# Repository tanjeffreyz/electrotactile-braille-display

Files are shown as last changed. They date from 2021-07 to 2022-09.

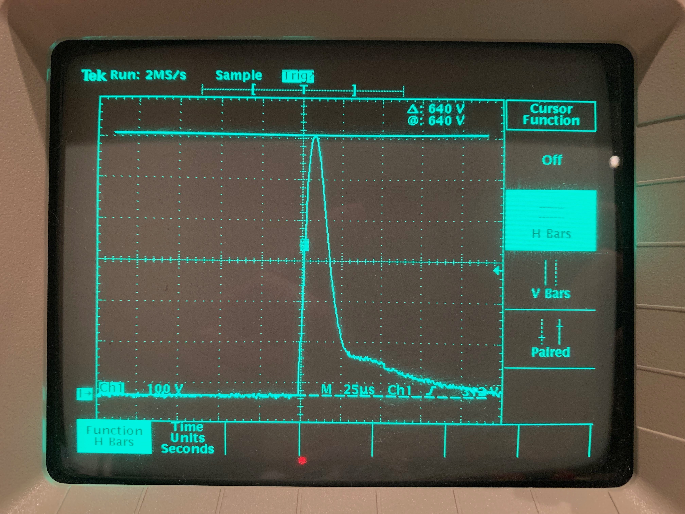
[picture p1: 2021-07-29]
images/oscilloscope_readings/IMG_0131.JPG

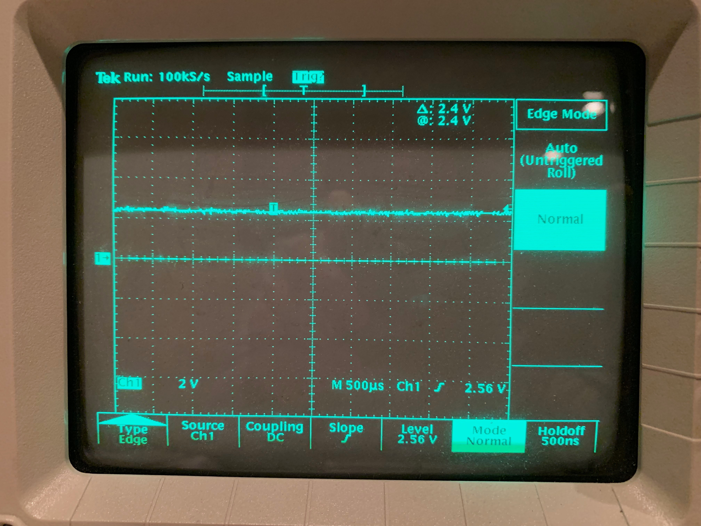
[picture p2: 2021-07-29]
images/oscilloscope_readings/IMG_0013.JPG

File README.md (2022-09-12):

<h1 align="center">Electrotactile Braille Display</h1> 

The Electrotactile Braille Display (ETBD) is a refreshable braille display that uses electrical pulses to simulate the feeling of braille dots on the user's fingertips. 
Because it has no moving parts, the ETBD has the potential to be much lighter, thinner, and cheaper compared to mechanical braille displays, which use physical braille pins.
 
<div align="center">
  
</div>
<br>
<div align="center">
  <a href="https://tanjeffreyz.github.io/electrotactile-braille-display"><b>Click here to view this project's full description</b></a>
</div>

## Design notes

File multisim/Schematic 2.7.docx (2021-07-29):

Schematic of Latest Prototype

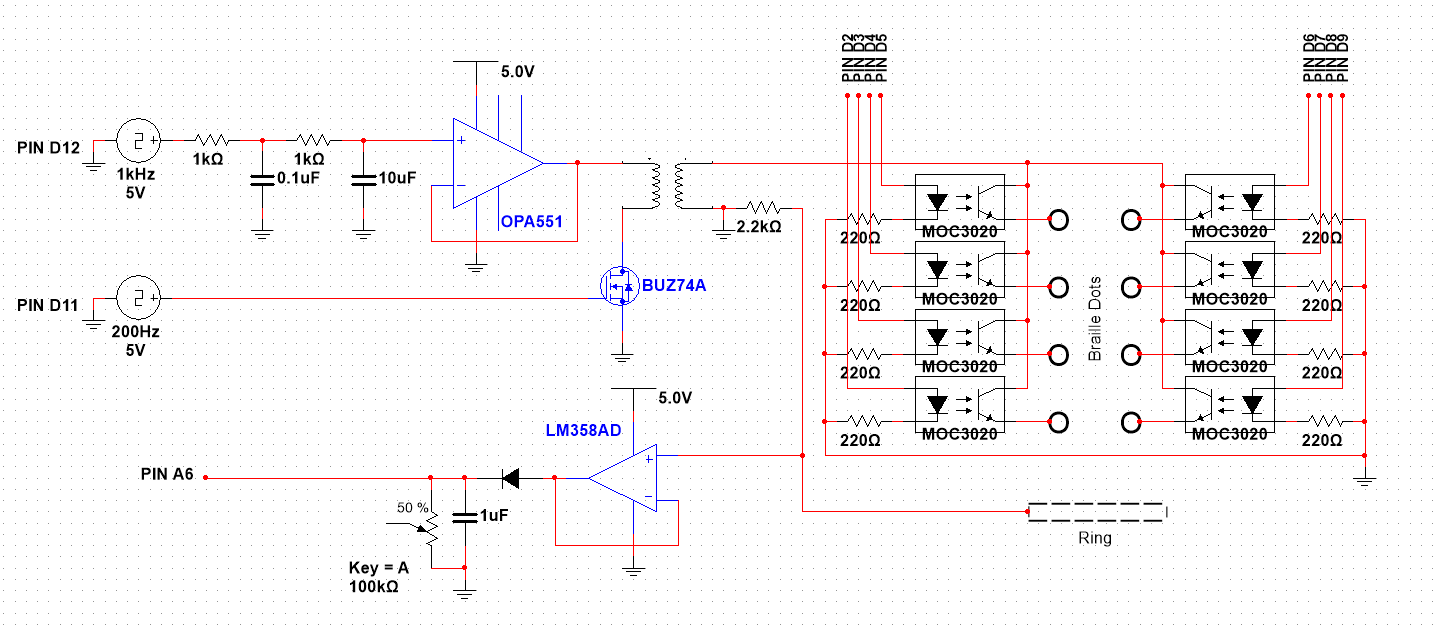
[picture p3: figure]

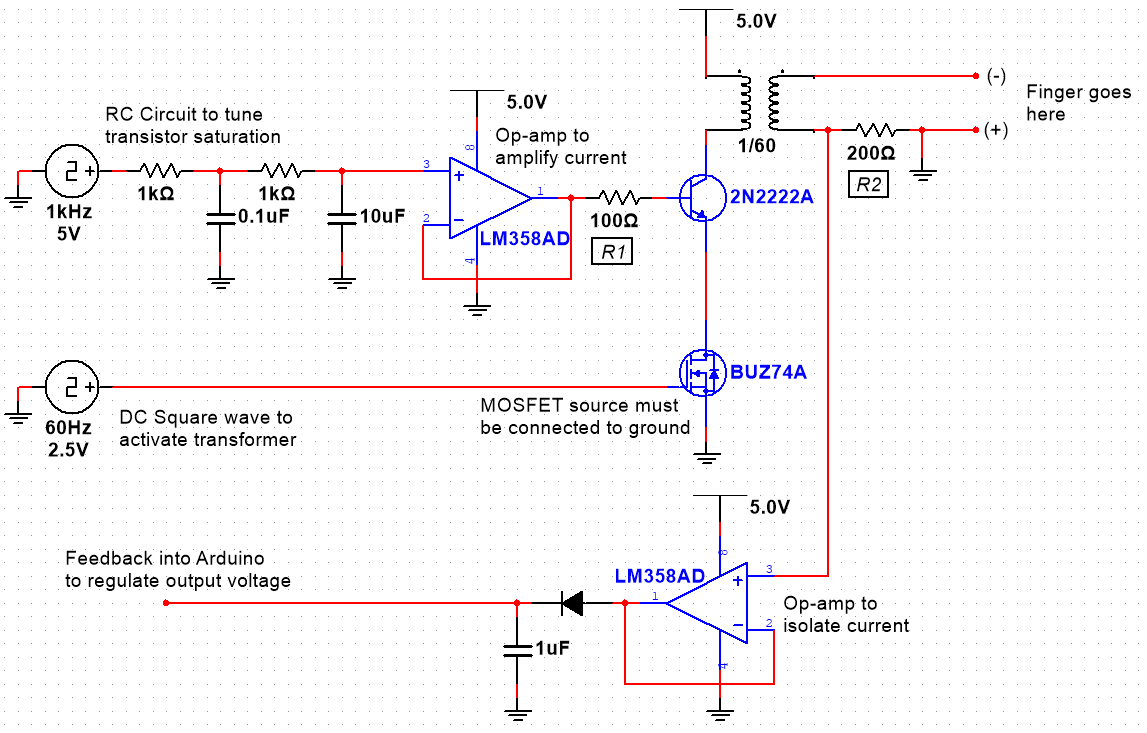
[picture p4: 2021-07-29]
images/schematics/Schematic v2.2.PNG

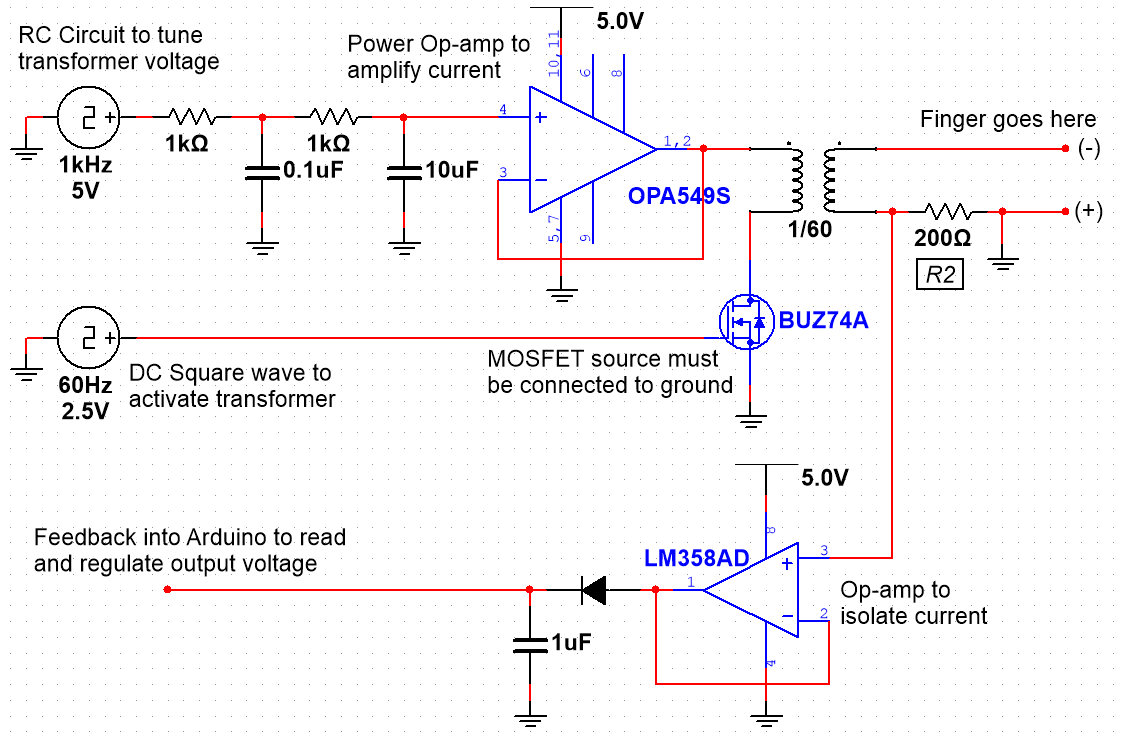
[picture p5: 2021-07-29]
images/schematics/Schematic v2.3.PNG

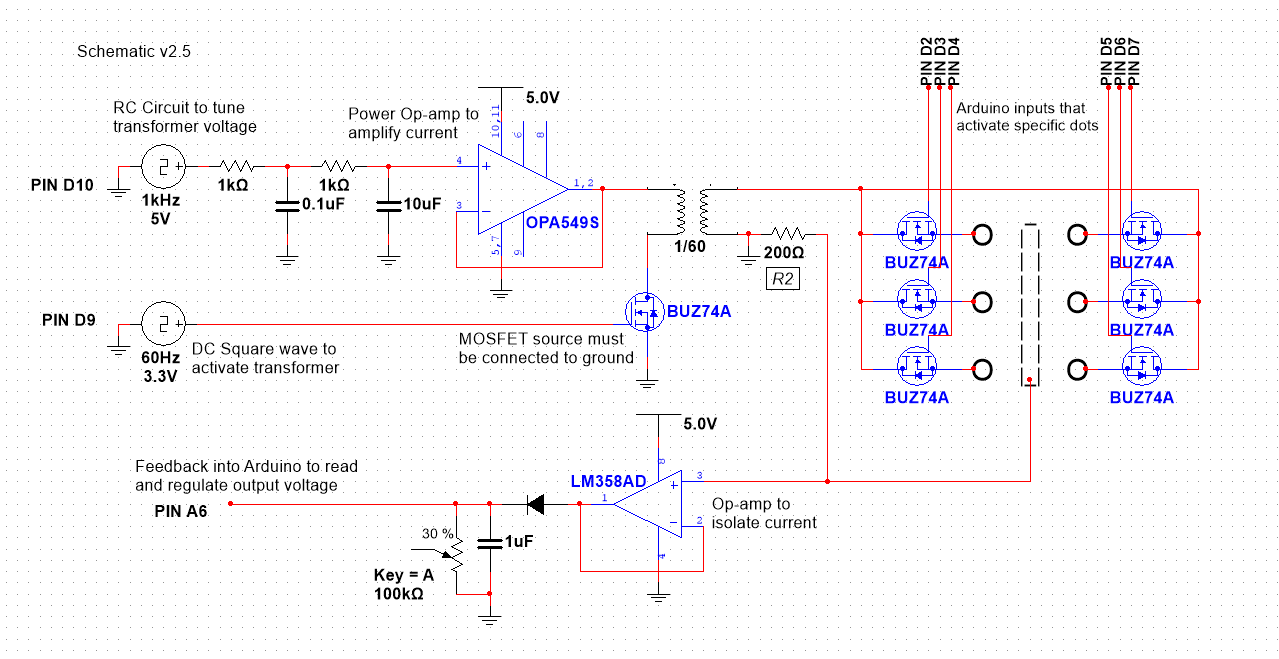
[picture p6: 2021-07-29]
images/schematics/Schematic v2.5.png

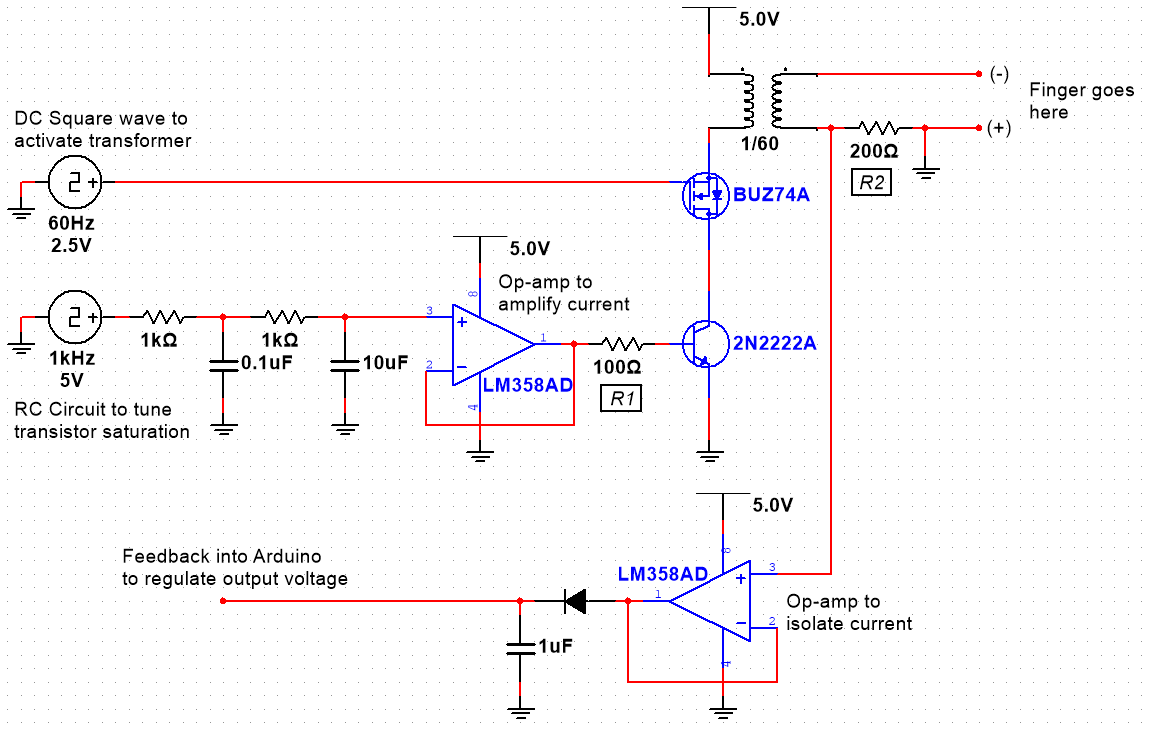
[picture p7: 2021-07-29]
images/schematics/Schematic v2.1.PNG

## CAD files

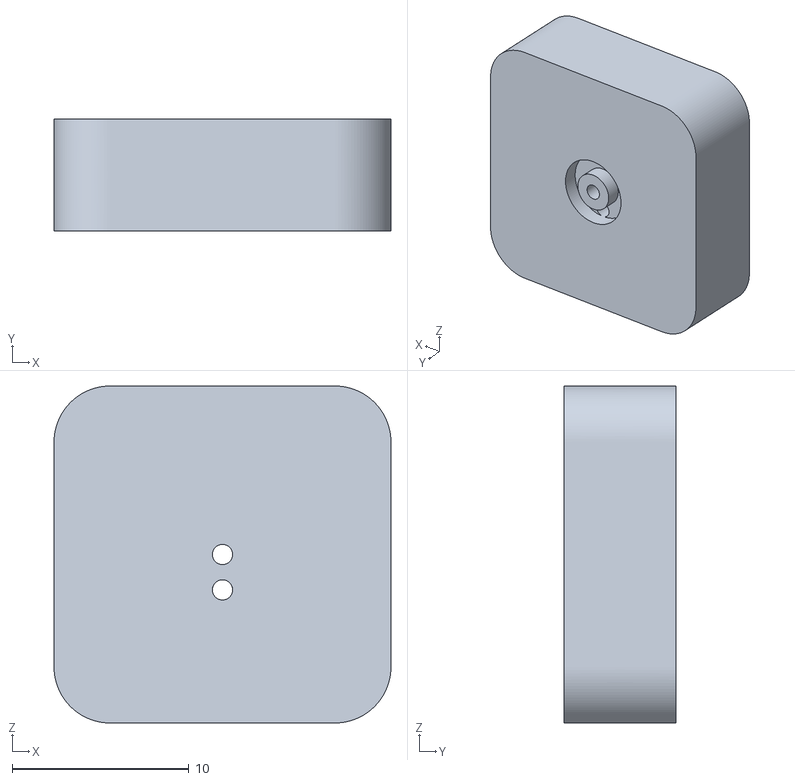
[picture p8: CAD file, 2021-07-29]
cad/Unit_v3.stl
19.0 x 6.35 x 19.0

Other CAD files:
cad/Unit_v3-1.dwg
cad/OldVersions/Unit_v3-1.0001.dwg
cad/Unit_v2.stl
cad/Unit_v1.stl
cad/OldVersions/Unit_v1.0001.ipt
cad/Unit_v1.ipt
cad/Unit_v2.ipt
cad/Unit_v3.ipt

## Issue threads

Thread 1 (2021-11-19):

Help to create a new braille device

discapacidad5, 2021-11-19:
Help to create a new braille device

Hi, I don't speak English, I'm using the google translator, I hope they understand me, my language is Spanish

I am developing a braille line with the ardiuno IDE and esp32 I have all the hardware but my problem is precisely that I do not fear how to communicate with the esp32
I have tried to connect the serial monitor of ardiuno and connect the esp32 by bluetooth and in the output of the serial port I get pure question marks and unreadable characters
I would like help to develop the software that would go in the esp32 that exchange data with the devices

my project consists of a very low cost braille display probably anyone can manufacture with less than $ 50 the idea is to create everything and make it available so that anyone can print their own braille display on a 3d printer and added the esp32 card and the driver can make your own braille line I hope someone can help me

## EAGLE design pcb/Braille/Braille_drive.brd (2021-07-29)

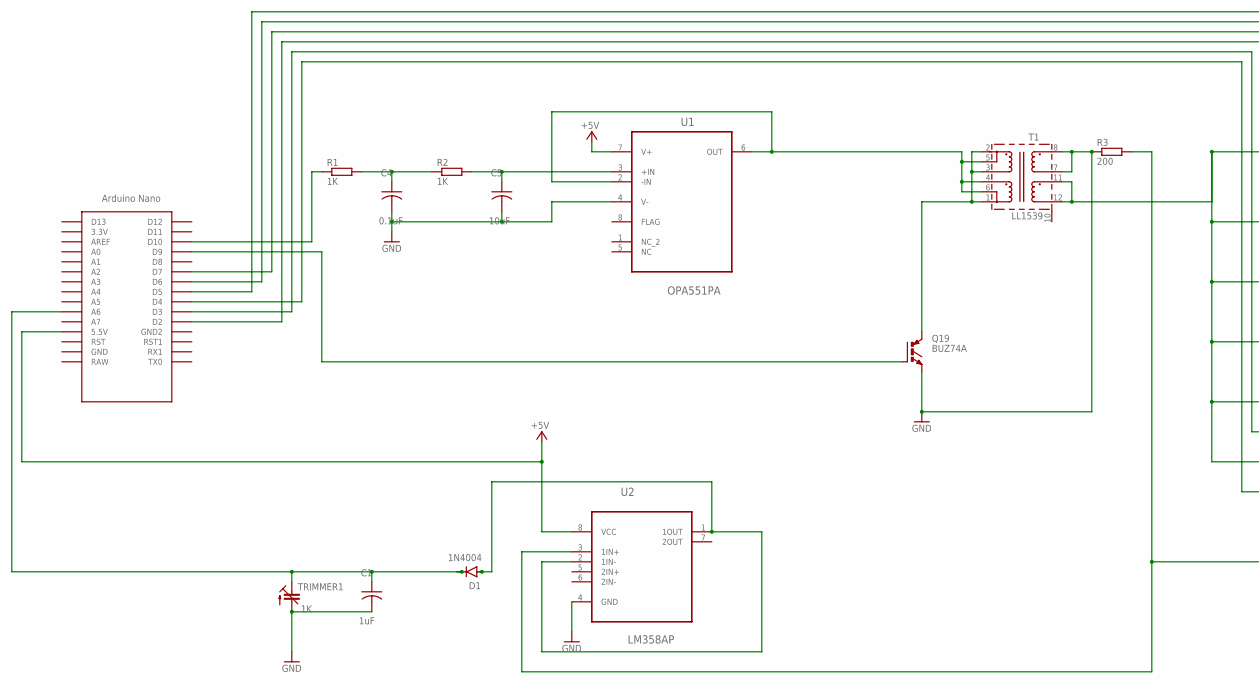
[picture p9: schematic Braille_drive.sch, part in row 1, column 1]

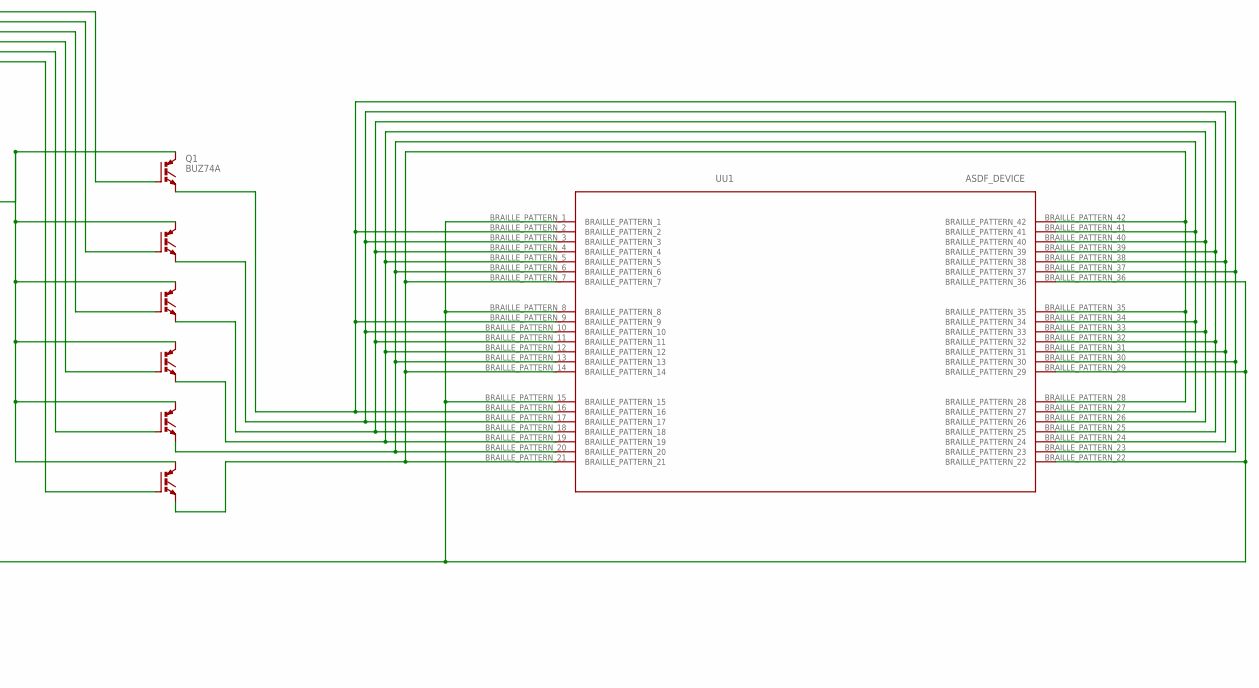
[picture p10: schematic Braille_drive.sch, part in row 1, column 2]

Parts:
C1: 1uF; CAP_RADIAL_2MM
C4: 0.1uF; CAP_RADIAL_2MM
C5: 10uF; CAP_RADIAL_2MM
D1: 1N4004; DO-41
Q1, Q2, Q3, Q4, Q5, Q6, Q19: BUZ74A; TO220AV
R1, R2: 1K; 0204V
R3: 200; 0204V
T1: LL1539
TRIMMER1: 1K; CTRIM3040.452
U1: OPA551PA; DIP254P762X508-8
U2: LM358AP; DIP254P762X508-8
U$1: NANO
UU1: ASDF_DEVICE; BRAILLE_PATTERN1

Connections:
+5V: U1.7 (V+), U2.8 (VCC), U$1.5V (5.5V)
GND: C1.2, C4.2, C5.2, Q19.E, R3.1, T1.7, T1.8, TRIMMER1.2 (A), U1.4 (V-), U2.4 (GND)
unnamed: R1.1, U$1.D10
unnamed: C4.1, R1.2, R2.1
unnamed: C5.1, R2.2, U1.3 (+IN)
unnamed: T1.4, T1.5, T1.6, U1.2 (-IN), U1.6 (OUT)
unnamed: Q19.C, T1.1, T1.2, T1.3
unnamed: Q19.G, U$1.D9
unnamed: D1.A, U2.1 (1OUT), U2.2 (1IN-)
unnamed: C1.1, D1.C, TRIMMER1.1A (E), U$1.A6
unnamed: Q6.G, U$1.D4
unnamed: Q5.G, U$1.D3
unnamed: Q1.C, Q2.C, Q3.C, Q4.C, Q5.C, Q6.C, T1.11, T1.12
unnamed: Q4.G, U$1.D2
unnamed: Q6.E, UU1.BRAILLE_PATTERN_7, UU1.BRAILLE_PATTERN_14, UU1.BRAILLE_PATTERN_21, UU1.BRAILLE_PATTERN_28, UU1.BRAILLE_PATTERN_35, UU1.BRAILLE_PATTERN_42
unnamed: Q3.G, U$1.D7
unnamed: Q2.G, U$1.D6
unnamed: Q1.G, U$1.D5
unnamed: R3.2, U2.3 (1IN+), UU1.BRAILLE_PATTERN_1, UU1.BRAILLE_PATTERN_8, UU1.BRAILLE_PATTERN_15, UU1.BRAILLE_PATTERN_22, UU1.BRAILLE_PATTERN_29, UU1.BRAILLE_PATTERN_36
unnamed: Q5.E, UU1.BRAILLE_PATTERN_6, UU1.BRAILLE_PATTERN_13, UU1.BRAILLE_PATTERN_20, UU1.BRAILLE_PATTERN_27, UU1.BRAILLE_PATTERN_34, UU1.BRAILLE_PATTERN_41
unnamed: Q1.E, UU1.BRAILLE_PATTERN_2, UU1.BRAILLE_PATTERN_9, UU1.BRAILLE_PATTERN_16, UU1.BRAILLE_PATTERN_23, UU1.BRAILLE_PATTERN_30, UU1.BRAILLE_PATTERN_37
unnamed: Q4.E, UU1.BRAILLE_PATTERN_5, UU1.BRAILLE_PATTERN_12, UU1.BRAILLE_PATTERN_19, UU1.BRAILLE_PATTERN_26, UU1.BRAILLE_PATTERN_33, UU1.BRAILLE_PATTERN_40
unnamed: Q3.E, UU1.BRAILLE_PATTERN_4, UU1.BRAILLE_PATTERN_11, UU1.BRAILLE_PATTERN_18, UU1.BRAILLE_PATTERN_25, UU1.BRAILLE_PATTERN_32, UU1.BRAILLE_PATTERN_39
unnamed: Q2.E, UU1.BRAILLE_PATTERN_3, UU1.BRAILLE_PATTERN_10, UU1.BRAILLE_PATTERN_17, UU1.BRAILLE_PATTERN_24, UU1.BRAILLE_PATTERN_31, UU1.BRAILLE_PATTERN_38

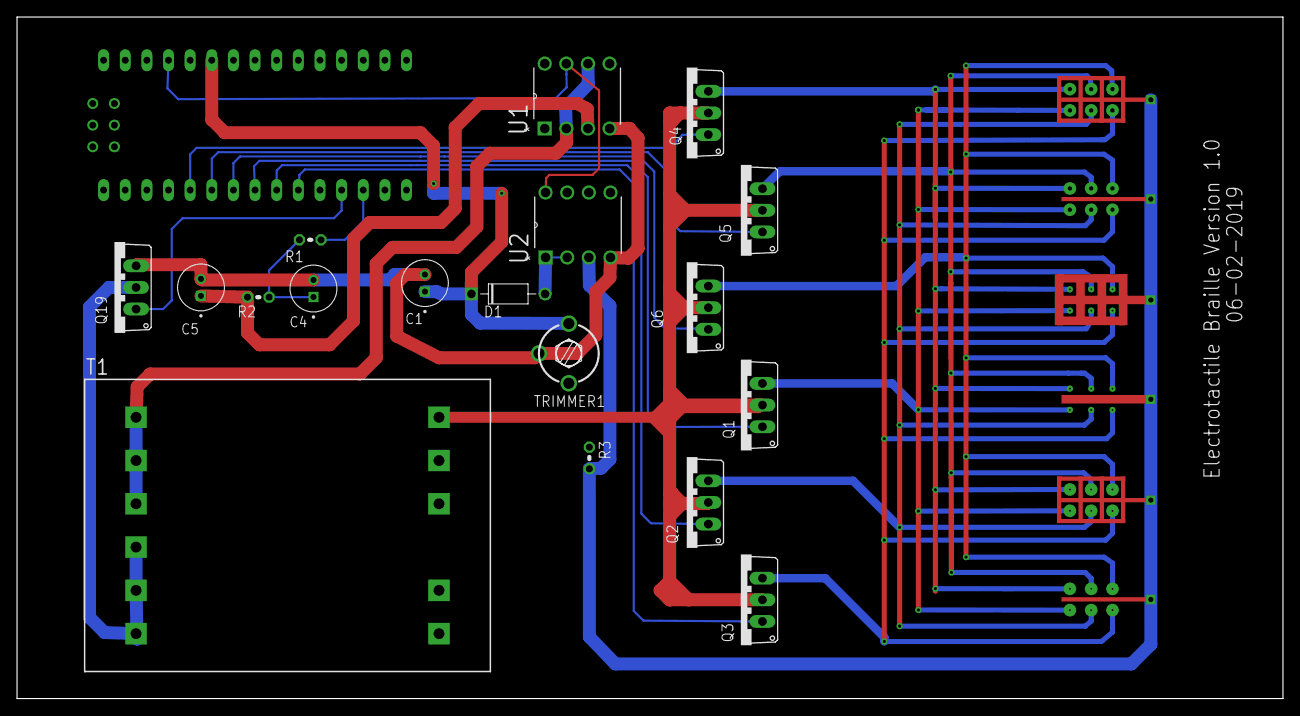
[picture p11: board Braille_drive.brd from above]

Board: 2 copper layers, 148.6 x 80.0 mm, 20 parts (0 on the bottom side), 24 nets.

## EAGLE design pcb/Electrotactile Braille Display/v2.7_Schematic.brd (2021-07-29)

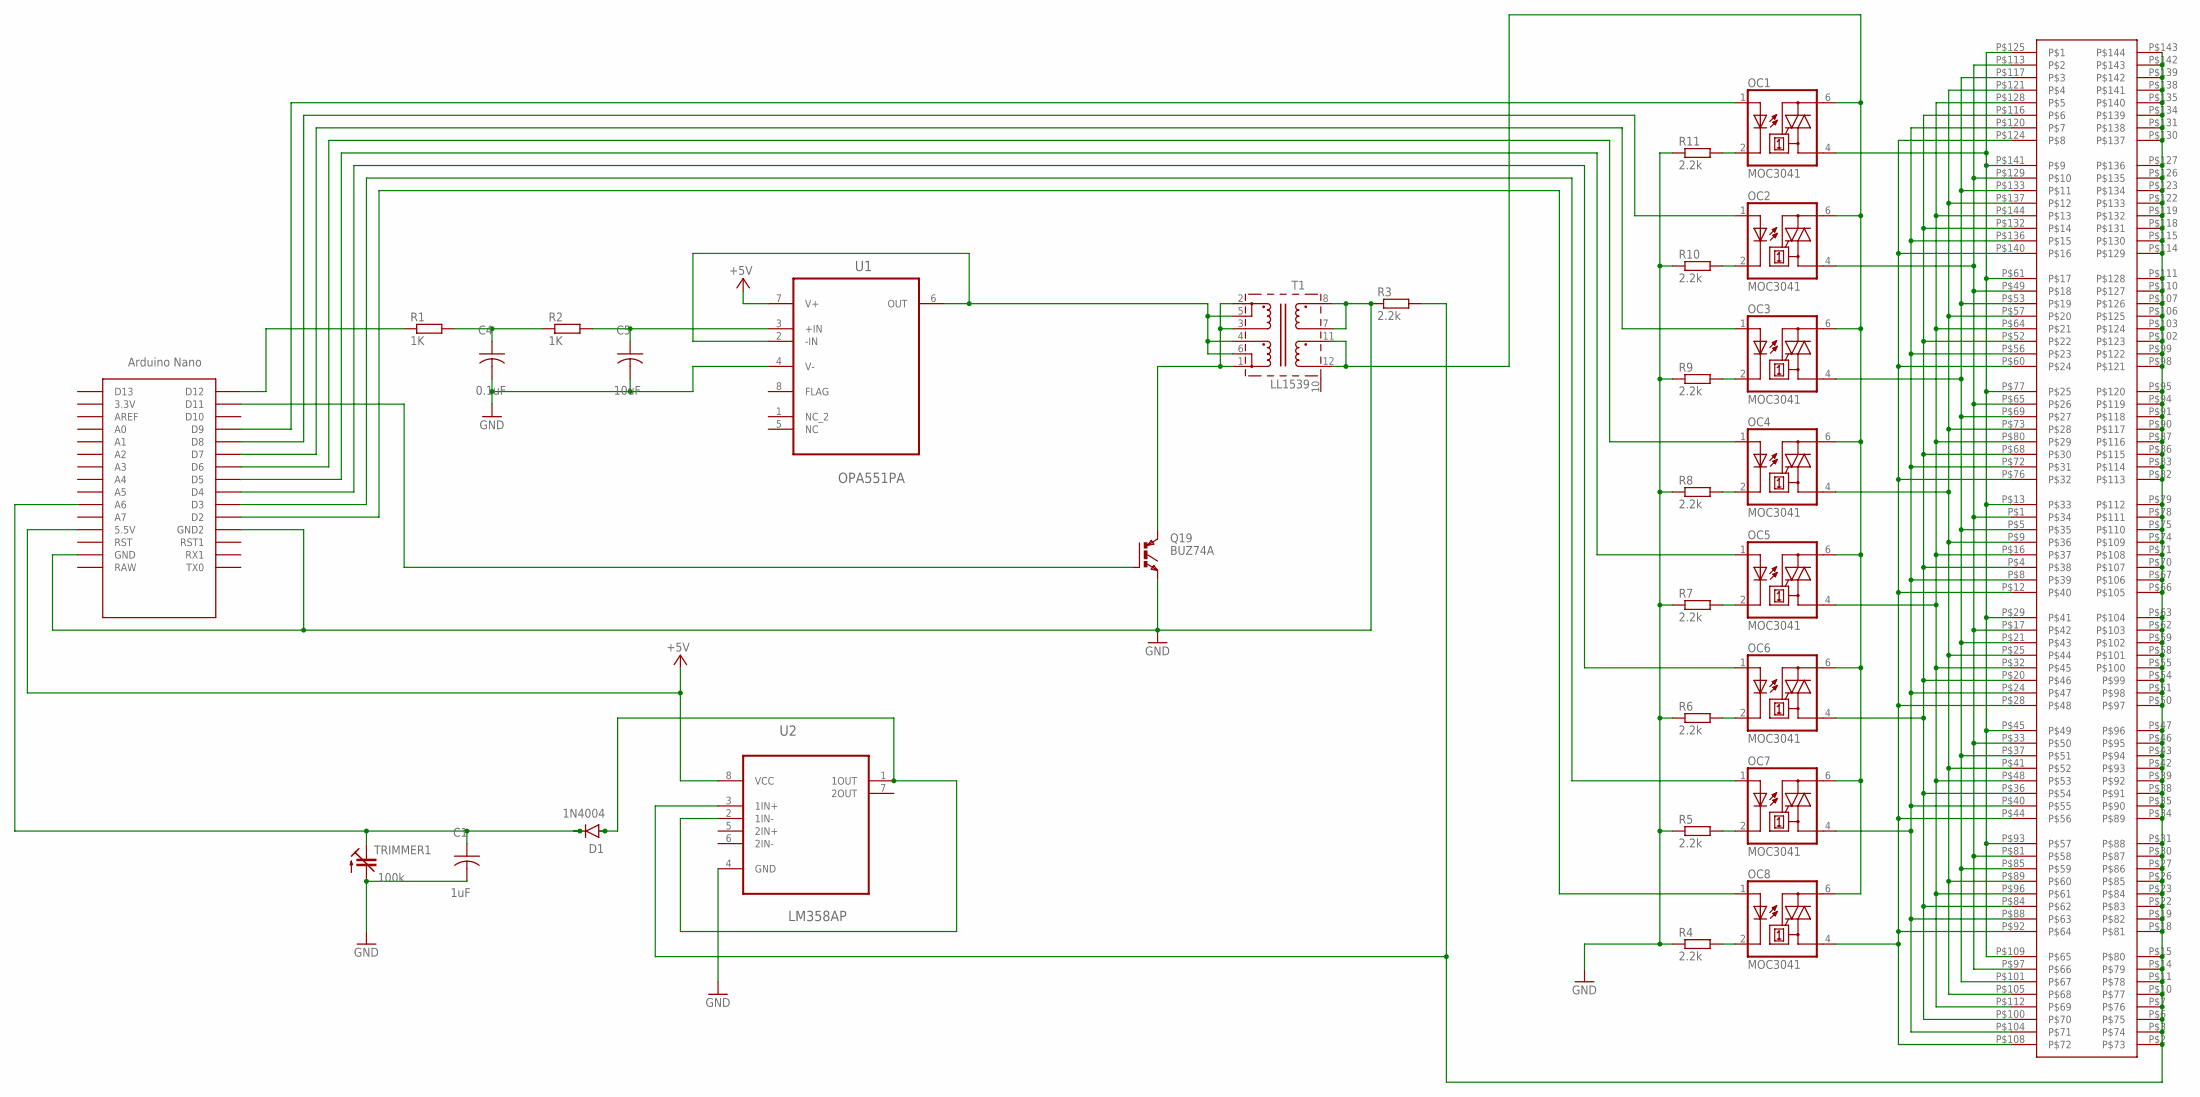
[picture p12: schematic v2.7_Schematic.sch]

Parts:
C1: 1uF; CAP_RADIAL_2MM
C4: 0.1uF; CAP_RADIAL_2MM
C5: 10uF; CAP_RADIAL_2MM
D1: 1N4004; DO-41
OC1, OC2, OC3, OC4, OC5, OC6, OC7, OC8: MOC3041; DIL06
Q19: BUZ74A; TO220AV
R1, R2: 1K; 0204V
R3, R4, R5, R6, R7, R8, R9, R10, R11: 2.2k; 0204V
T1: LL1539
TRIMMER1: 100k; CTRIM3040.452
U1: OPA551PA; DIP254P762X508-8
U2: LM358AP; DIP254P762X508-8
U$1: NANO
U$2: DOTS_V2

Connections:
+5V: U1.7 (V+), U2.8 (VCC), U$1.5V (5.5V)
GND: C1.2, C4.2, C5.2, Q19.E, R3.1, R4.1, R5.1, R6.1, R7.1, R8.1, R9.1, R10.1, R11.1, T1.7, T1.8, TRIMMER1.2 (A), U1.4 (V-), U2.4 (GND), U$1.GND, U$1.GND1 (GND2)
unnamed: OC7.2 (C), R5.2
unnamed: C4.1, R1.2, R2.1
unnamed: C5.1, R2.2, U1.3 (+IN)
unnamed: T1.4, T1.5, T1.6, U1.2 (-IN), U1.6 (OUT)
unnamed: Q19.C, T1.1, T1.2, T1.3
unnamed: Q19.G, U$1.D11
unnamed: D1.A, U2.1 (1OUT), U2.2 (1IN-)
unnamed: C1.1, D1.C, TRIMMER1.1A (E), U$1.A6
unnamed: OC8.1 (A), U$1.D2
unnamed: OC7.1 (A), U$1.D3
unnamed: OC2.1 (A), U$1.D8
unnamed: OC6.1 (A), U$1.D4
unnamed: R1.1, U$1.D12
unnamed: OC5.1 (A), U$1.D5
unnamed: OC4.1 (A), U$1.D6
unnamed: OC3.1 (A), U$1.D7
unnamed: R3.2, U2.3 (1IN+), U$2.P$2, U$2.P$3, U$2.P$6, U$2.P$7, U$2.P$10, U$2.P$11, U$2.P$14, U$2.P$15, U$2.P$18, U$2.P$19, U$2.P$22, U$2.P$23, U$2.P$26, U$2.P$27, U$2.P$30, U$2.P$31, U$2.P$34, U$2.P$35, U$2.P$38, U$2.P$39, U$2.P$42, U$2.P$43, U$2.P$46, U$2.P$47, U$2.P$50, U$2.P$51, U$2.P$54, U$2.P$55, U$2.P$58, U$2.P$59, U$2.P$62, U$2.P$63, U$2.P$66, U$2.P$67, U$2.P$70, U$2.P$71, U$2.P$74, U$2.P$75, U$2.P$78, U$2.P$79, U$2.P$82, U$2.P$83, U$2.P$86, U$2.P$87, U$2.P$90, U$2.P$91, U$2.P$94, U$2.P$95, U$2.P$98, U$2.P$99, U$2.P$102, U$2.P$103, U$2.P$106, U$2.P$107, U$2.P$110, U$2.P$111, U$2.P$114, U$2.P$115, U$2.P$118, U$2.P$119, U$2.P$122, U$2.P$123, U$2.P$126, U$2.P$127, U$2.P$130, U$2.P$131, U$2.P$134, U$2.P$135, U$2.P$138, U$2.P$139, U$2.P$142, U$2.P$143
unnamed: OC1.6 (A2), OC2.6 (A2), OC3.6 (A2), OC4.6 (A2), OC5.6 (A2), OC6.6 (A2), OC7.6 (A2), OC8.6 (A2), T1.11, T1.12
unnamed: OC4.4 (A1), U$2.P$9, U$2.P$25, U$2.P$41, U$2.P$57, U$2.P$73, U$2.P$89, U$2.P$105, U$2.P$121, U$2.P$137
unnamed: OC1.1 (A), U$1.D9
unnamed: OC2.4 (A1), U$2.P$1, U$2.P$17, U$2.P$33, U$2.P$49, U$2.P$65, U$2.P$81, U$2.P$97, U$2.P$113, U$2.P$129
unnamed: OC3.4 (A1), U$2.P$5, U$2.P$21, U$2.P$37, U$2.P$53, U$2.P$69, U$2.P$85, U$2.P$101, U$2.P$117, U$2.P$133
unnamed: OC5.4 (A1), U$2.P$16, U$2.P$32, U$2.P$48, U$2.P$64, U$2.P$80, U$2.P$96, U$2.P$112, U$2.P$128, U$2.P$144
unnamed: OC6.4 (A1), U$2.P$4, U$2.P$20, U$2.P$36, U$2.P$52, U$2.P$68, U$2.P$84, U$2.P$100, U$2.P$116, U$2.P$132
unnamed: OC7.4 (A1), U$2.P$8, U$2.P$24, U$2.P$40, U$2.P$56, U$2.P$72, U$2.P$88, U$2.P$104, U$2.P$120, U$2.P$136
unnamed: OC8.4 (A1), U$2.P$12, U$2.P$28, U$2.P$44, U$2.P$60, U$2.P$76, U$2.P$92, U$2.P$108, U$2.P$124, U$2.P$140
unnamed: OC8.2 (C), R4.2
unnamed: OC1.4 (A1), U$2.P$13, U$2.P$29, U$2.P$45, U$2.P$61, U$2.P$77, U$2.P$93, U$2.P$109, U$2.P$125, U$2.P$141
unnamed: OC6.2 (C), R6.2
unnamed: OC5.2 (C), R7.2
unnamed: OC4.2 (C), R8.2
unnamed: OC3.2 (C), R9.2
unnamed: OC2.2 (C), R10.2
unnamed: OC1.2 (C), R11.2

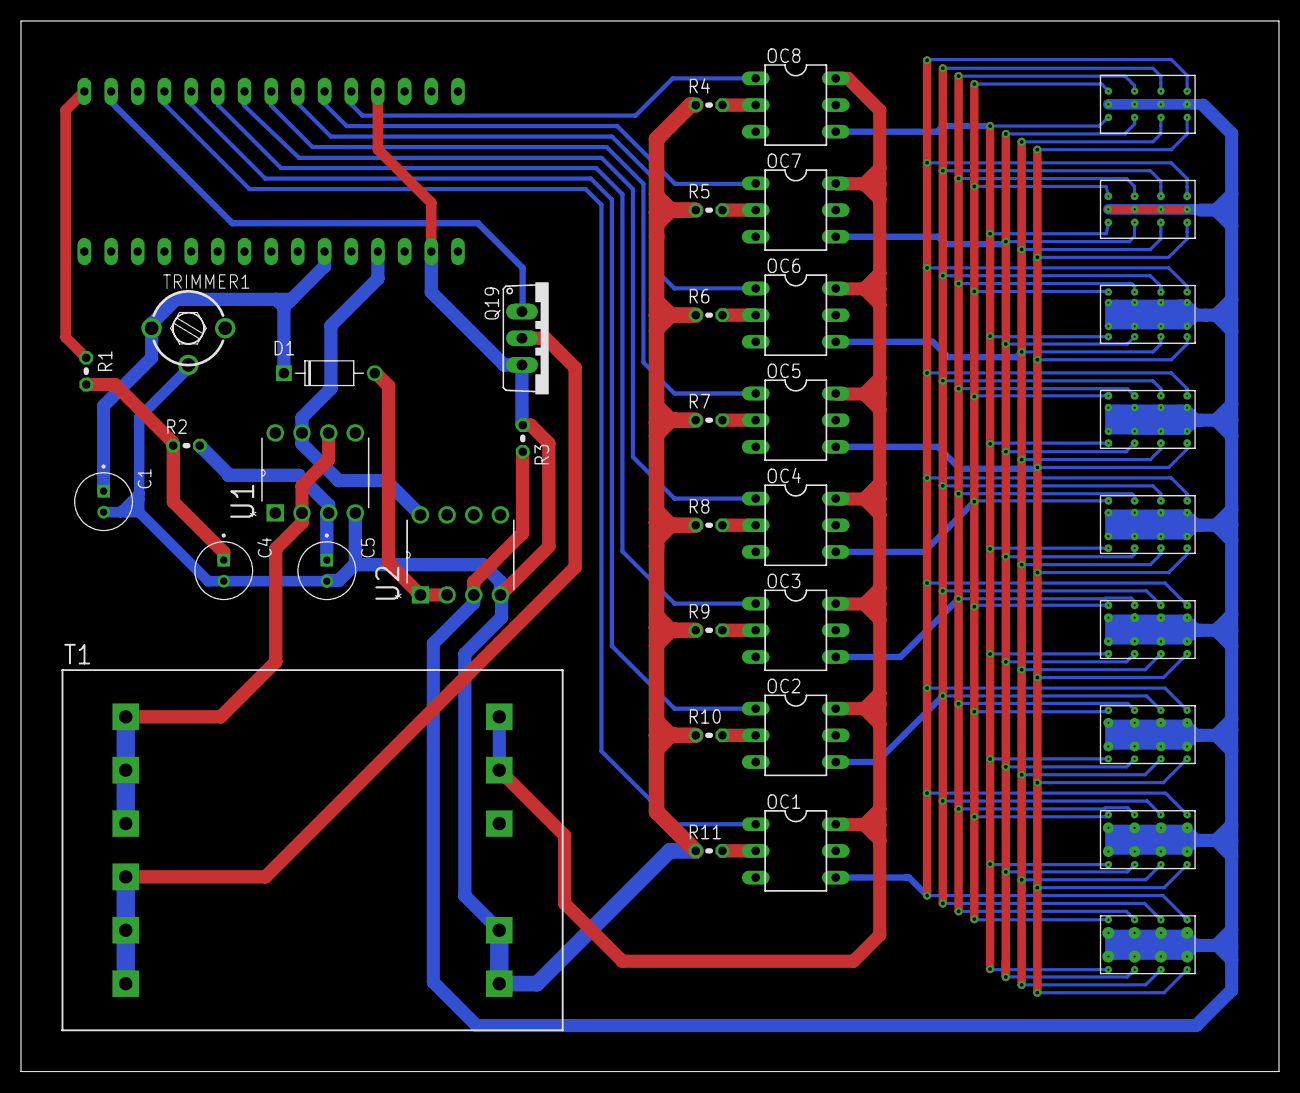
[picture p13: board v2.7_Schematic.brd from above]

Board: 2 copper layers, 119.8 x 100.0 mm, 30 parts (0 on the bottom side), 36 nets.

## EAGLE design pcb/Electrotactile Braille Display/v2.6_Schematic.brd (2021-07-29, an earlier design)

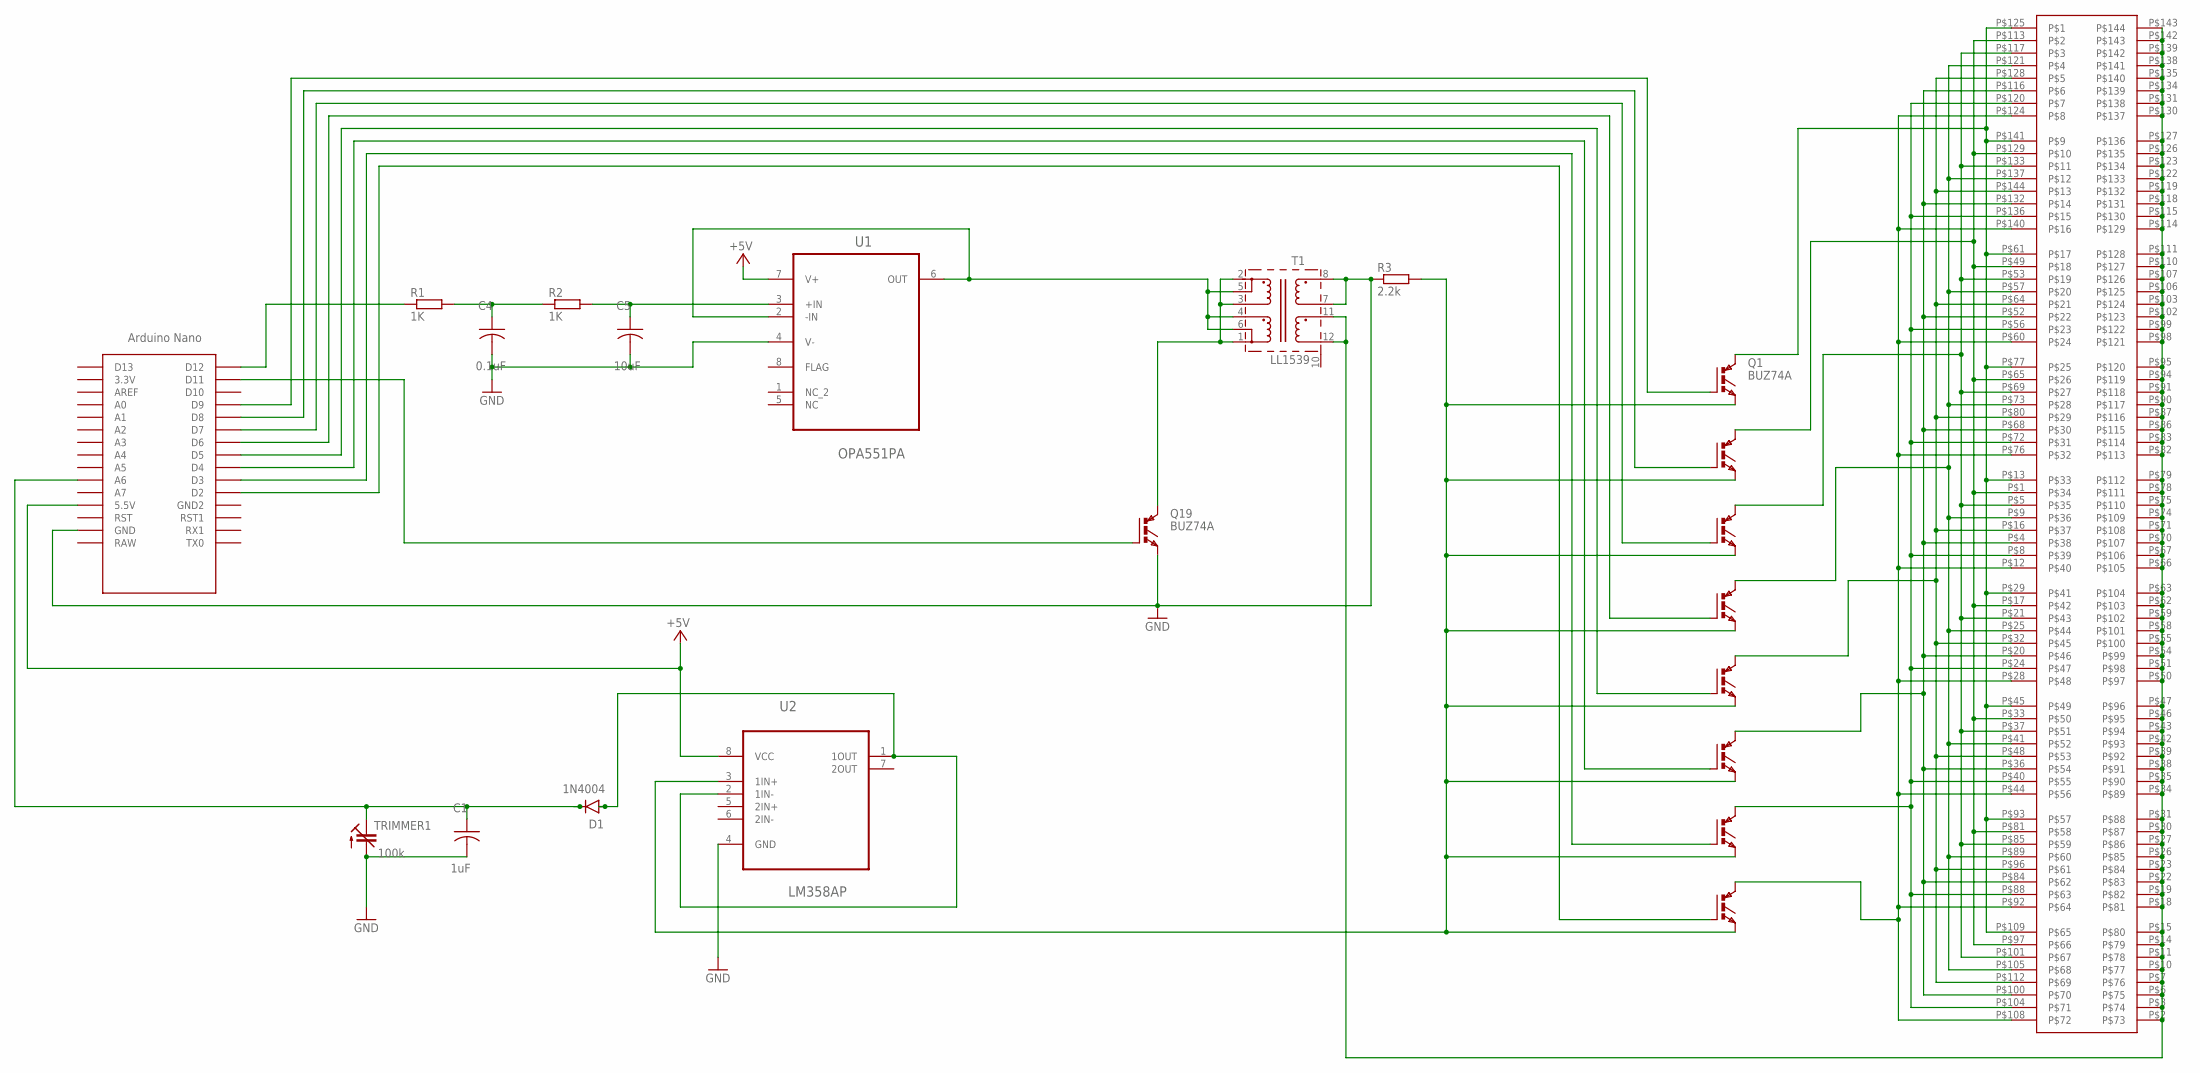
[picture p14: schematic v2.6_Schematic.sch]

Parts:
C1: 1uF; CAP_RADIAL_2MM
C4: 0.1uF; CAP_RADIAL_2MM
C5: 10uF; CAP_RADIAL_2MM
D1: 1N4004; DO-41
Q1, Q2, Q3, Q4, Q5, Q6, Q7, Q8, Q19: BUZ74A; TO220AV
R1, R2: 1K; 0204V
R3: 2.2k; 0204V
T1: LL1539
TRIMMER1: 100k; CTRIM3040.452
U1: OPA551PA; DIP254P762X508-8
U2: LM358AP; DIP254P762X508-8
U$1: NANO
U$2: DOTS_V2

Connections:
+5V: U1.7 (V+), U2.8 (VCC), U$1.5V (5.5V)
GND: C1.2, C4.2, C5.2, Q19.E, R3.1, T1.7, T1.8, TRIMMER1.2 (A), U1.4 (V-), U2.4 (GND), U$1.GND
unnamed: T1.11, T1.12, U$2.P$2, U$2.P$3, U$2.P$6, U$2.P$7, U$2.P$10, U$2.P$11, U$2.P$14, U$2.P$15, U$2.P$18, U$2.P$19, U$2.P$22, U$2.P$23, U$2.P$26, U$2.P$27, U$2.P$30, U$2.P$31, U$2.P$34, U$2.P$35, U$2.P$38, U$2.P$39, U$2.P$42, U$2.P$43, U$2.P$46, U$2.P$47, U$2.P$50, U$2.P$51, U$2.P$54, U$2.P$55, U$2.P$58, U$2.P$59, U$2.P$62, U$2.P$63, U$2.P$66, U$2.P$67, U$2.P$70, U$2.P$71, U$2.P$74, U$2.P$75, U$2.P$78, U$2.P$79, U$2.P$82, U$2.P$83, U$2.P$86, U$2.P$87, U$2.P$90, U$2.P$91, U$2.P$94, U$2.P$95, U$2.P$98, U$2.P$99, U$2.P$102, U$2.P$103, U$2.P$106, U$2.P$107, U$2.P$110, U$2.P$111, U$2.P$114, U$2.P$115, U$2.P$118, U$2.P$119, U$2.P$122, U$2.P$123, U$2.P$126, U$2.P$127, U$2.P$130, U$2.P$131, U$2.P$134, U$2.P$135, U$2.P$138, U$2.P$139, U$2.P$142, U$2.P$143
unnamed: C4.1, R1.2, R2.1
unnamed: C5.1, R2.2, U1.3 (+IN)
unnamed: T1.4, T1.5, T1.6, U1.2 (-IN), U1.6 (OUT)
unnamed: Q19.C, T1.1, T1.2, T1.3
unnamed: Q19.G, U$1.D11
unnamed: D1.A, U2.1 (1OUT), U2.2 (1IN-)
unnamed: C1.1, D1.C, TRIMMER1.1A (E), U$1.A6
unnamed: Q8.G, U$1.D2
unnamed: Q7.G, U$1.D3
unnamed: Q2.G, U$1.D8
unnamed: Q6.G, U$1.D4
unnamed: R1.1, U$1.D12
unnamed: Q5.G, U$1.D5
unnamed: Q4.G, U$1.D6
unnamed: Q3.G, U$1.D7
unnamed: Q1.E, Q2.E, Q3.E, Q4.E, Q5.E, Q6.E, Q7.E, Q8.E, R3.2, U2.3 (1IN+)
unnamed: Q4.C, U$2.P$9, U$2.P$25, U$2.P$41, U$2.P$57, U$2.P$73, U$2.P$89, U$2.P$105, U$2.P$121, U$2.P$137
unnamed: Q1.G, U$1.D9
unnamed: Q2.C, U$2.P$1, U$2.P$17, U$2.P$33, U$2.P$49, U$2.P$65, U$2.P$81, U$2.P$97, U$2.P$113, U$2.P$129
unnamed: Q3.C, U$2.P$5, U$2.P$21, U$2.P$37, U$2.P$53, U$2.P$69, U$2.P$85, U$2.P$101, U$2.P$117, U$2.P$133
unnamed: Q5.C, U$2.P$16, U$2.P$32, U$2.P$48, U$2.P$64, U$2.P$80, U$2.P$96, U$2.P$112, U$2.P$128, U$2.P$144
unnamed: Q6.C, U$2.P$4, U$2.P$20, U$2.P$36, U$2.P$52, U$2.P$68, U$2.P$84, U$2.P$100, U$2.P$116, U$2.P$132
unnamed: Q7.C, U$2.P$8, U$2.P$24, U$2.P$40, U$2.P$56, U$2.P$72, U$2.P$88, U$2.P$104, U$2.P$120, U$2.P$136
unnamed: Q8.C, U$2.P$12, U$2.P$28, U$2.P$44, U$2.P$60, U$2.P$76, U$2.P$92, U$2.P$108, U$2.P$124, U$2.P$140
unnamed: Q1.C, U$2.P$13, U$2.P$29, U$2.P$45, U$2.P$61, U$2.P$77, U$2.P$93, U$2.P$109, U$2.P$125, U$2.P$141

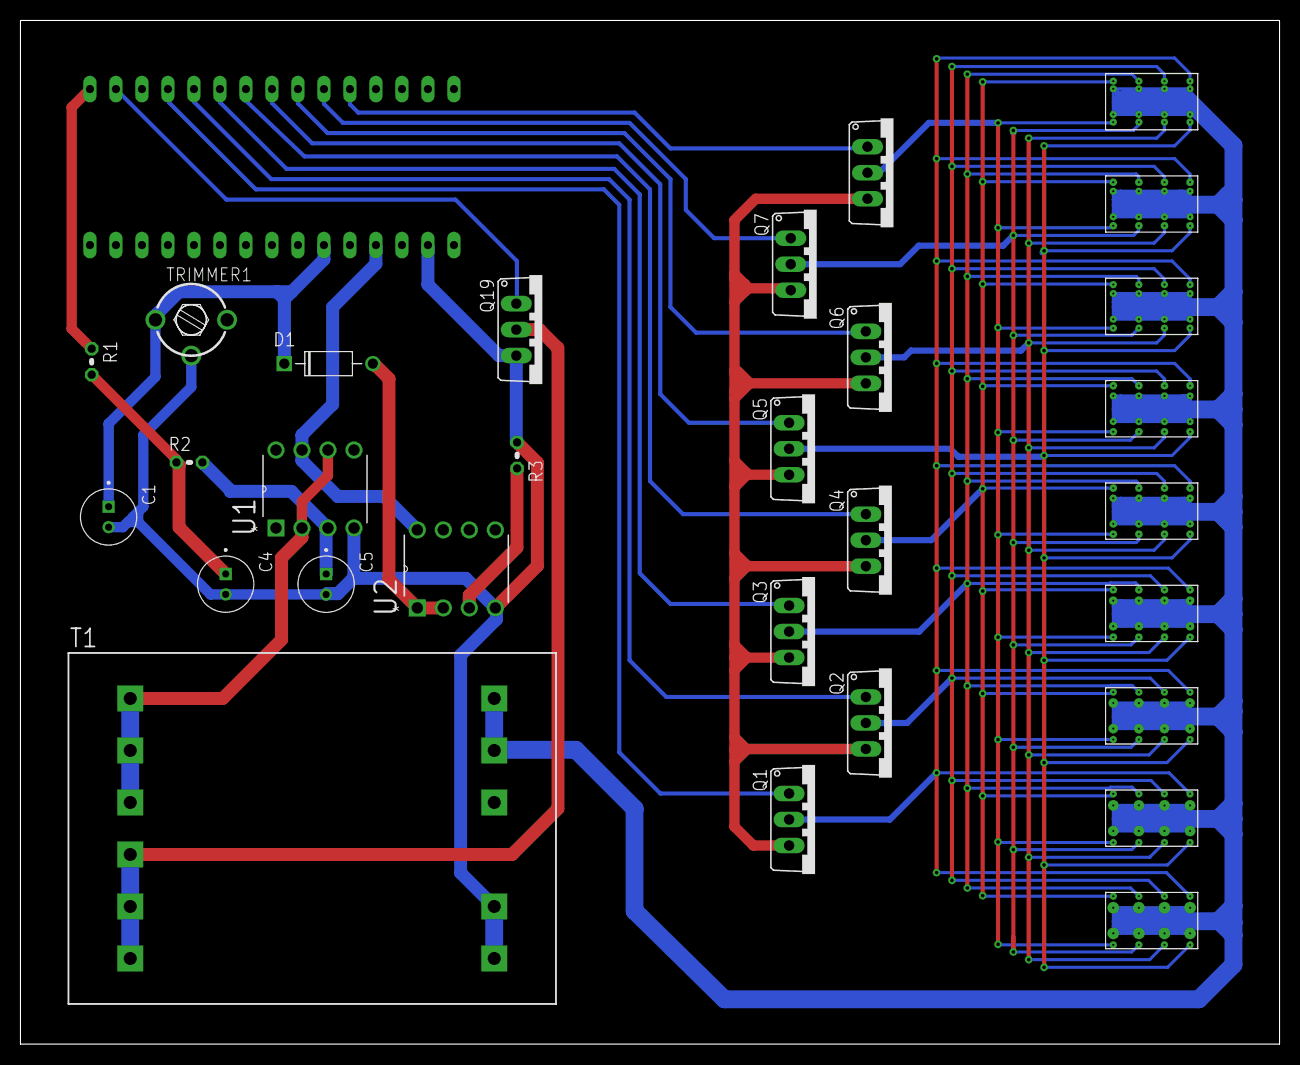
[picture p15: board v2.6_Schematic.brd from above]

Board: 2 copper layers, 123.0 x 100.0 mm, 22 parts (0 on the bottom side), 28 nets.

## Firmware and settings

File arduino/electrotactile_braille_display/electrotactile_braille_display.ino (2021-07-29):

/////////////////////
//    Variables    //
/////////////////////
const int timerFrequency = 20000;
const double timerPeriod = 1.0 / timerFrequency;

// RC circuit
const int frequencyRC = 1000;
double dutyCycleRC = 0.15;
double counterRC = 0.0;
boolean toggleRC = 0;   //0 = Low, 1 = High

// Transformer MOSFET
const int frequencySW = 200;
const double dutyCycleSW = 0.3;
double counterSW = 0.0;
boolean toggleSW = 0;   //0 = Low, 1 = High

// Feedback control
const double targetVoltage = 2.00;
const double kRC = 1.045;   // Scales the counter increments to counter period distortion. This was experimentally determined.
const double kP = 0.001;
const double kI = 0.0003;
double accumulatedError = 0.0;
const double kD = 0.0001;
double prevError = 0.0;


/////////////////////
//    Functions    //
/////////////////////
void setup() {
  pinMode(10, OUTPUT);    // Supplies voltage to transformer
  pinMode(9, OUTPUT);     // Square wave to activate transformer
  
  Serial.begin(1000000);
  
  noInterrupts();

  TCCR1A = 0;
  TCCR1B = 0;
  TCNT1  = 0;

  OCR1A = 799;   // Compare match register = 16*10^6 / 20000 - 1 for a frequency of 20k Hz
  TCCR1B |= (1 << WGM12);
  TCCR1B |= (1 << CS10);
  TIMSK1 |= (1 << OCIE1A);

  interrupts();
}

ISR(TIMER1_COMPA_vect) {
  counterRC += (timerPeriod * kRC);   // Increment = 1 / (frequency of timer) = 1 / 20000 = 0.00005
  counterSW += 0.00005;
}


void loop() {
  interrupts();

  // RC Signal
  if ((toggleRC) && (counterRC >= (1.0 - dutyCycleRC) / (double)frequencyRC)) {   //this waits for a period of time (time low) before turning the signal high, hence the (1.0 - dutyCycle) factor
    digitalWrite(10, HIGH);
    //Serial.println("High");
    counterRC = 0.0;
    toggleRC = 0;
  } else if ((!toggleRC) && (counterRC >= dutyCycleRC / (double)frequencyRC)) {   //this waits for a period of time (time high) before turning the signal low, hence the (dutyCycleRC) factor
    digitalWrite(10, LOW);
    //Serial.println("Low");
    counterRC = 0.0;
    toggleRC = 1;
  }

  // Square wave for transformer MOSFET
  if (toggleSW && counterSW >= (1.0 - dutyCycleSW) / (double)frequencySW) {   //this waits for a period of time (time low) before turning the signal high, hence the (1.0 - dutyCycle) factor
    digitalWrite(9, HIGH);
    counterSW = 0.0;
    toggleSW = 0;
  } else if (!toggleSW && counterSW >= dutyCycleSW / (double)frequencySW) {   //this waits for a period of time (time high) before turning the signal low, hence the (dutyCycleRC) factor
    digitalWrite(9, LOW);
    counterSW = 0.0;
    toggleSW = 1;
  }
 
  // Regulate output voltage
  int reading = analogRead(A6);
  if (reading >= 100) {   // Only regulate while finger is on the pad
    double currVoltage = reading / 1023.0;
    double currError = targetVoltage - currVoltage;
    accumulatedError += currError * timerPeriod;
    dutyCycleRC += kP * currError + kI * accumulatedError + kD * (currError - prevError);    // PID feedback control
    prevError = currError;
  } else {
    dutyCycleRC = 0.00;
  }

  // Cap the dutycycle
  if(dutyCycleRC >= 1.00) {
    dutyCycleRC = 1.00;
  } else if(dutyCycleRC <= 0.00) {
    dutyCycleRC = 0.00;
  }
}

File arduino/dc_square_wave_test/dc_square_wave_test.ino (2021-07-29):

int frequency = 1000;   //Frequency in Hz
double dutyCycle = 0.50;   //Duty cycle as a fraction

unsigned int timeHigh = (unsigned int)(1000000 * dutyCycle / frequency);
unsigned int timeLow = (unsigned int)(1000000 * (1.0 - dutyCycle) / frequency);

void setup() {
  // put your setup code here, to run once:
  pinMode(10, OUTPUT);
  Serial.begin(300);

  Serial.println(timeHigh);
  Serial.println(timeLow);
}

void loop() {
  // put your main code here, to run repeatedly:  
  digitalWrite(10, HIGH);
  delayMicroseconds(timeHigh);
  digitalWrite(10, LOW);
  delayMicroseconds(timeLow);
}

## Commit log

2021-07-29 uploaded etbd
    [Braille_drive.brd, Braille_drive.sch, Unit_v1.0001.ipt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]
2021-07-29 fixed some naming conventions
    [dc_square_wave_test.ino, rc_and_square_wave_test.ino]
2021-07-29 reverted, should update name now
    [pwm_to_analog_test.ino]
